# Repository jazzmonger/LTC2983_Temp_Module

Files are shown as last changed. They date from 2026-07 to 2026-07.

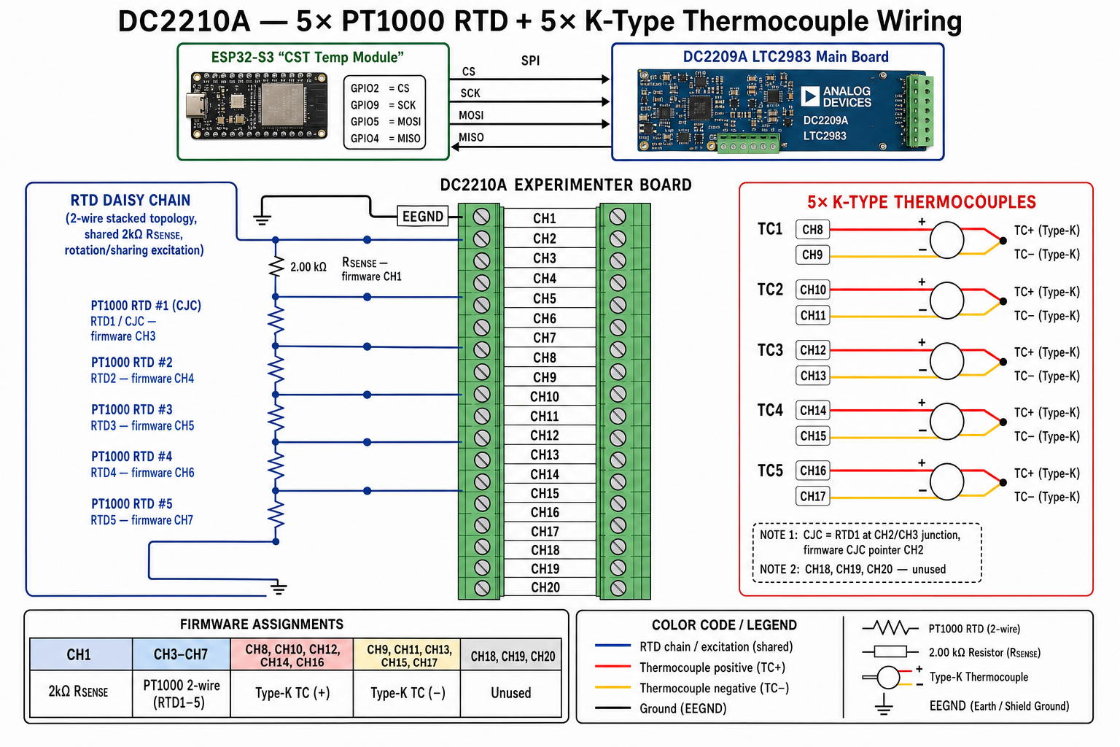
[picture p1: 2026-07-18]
schematics/dc2210a-5rtd-5tc-wiring.png

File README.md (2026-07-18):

# LTC2983 Temperature Module

ESPHome firmware and KiCad hardware designs for reading precision temperature sensors through the [Analog Devices LTC2983](https://www.analog.com/en/products/ltc2983.html) — a 20-channel multi-sensor ADC supporting RTDs, thermocouples, diodes, and thermistors.

This repo is a **standalone** ESPHome device that reads **5× PT1000 RTDs** and **5× K-type thermocouples** in one multi-channel conversion cycle, with per-channel fault sensors. The board and can be adapted to other sensor combinations on unused LTC2983 channels.

## Hardware

| Component | Description |
|---|---|
| **MCU** | ESP32-S3-DevKitC-1 class (16 MB flash, 8 MB octal PSRAM) |
| **Sensor IC** | LTC2983 |
| **Target layout** | Stacked 5 RTD + 5 TC topology ([DC2210A](schematics/dc2210a-5rtd-5tc-wiring.png) reference) |
| **Carrier PCB** | Custom [DC2209A1](KiCad/DC2209A1.kicad_sch) KiCad design — LTC2983 breakout with screw terminals and SPI header |

### SPI wiring (ESP32-S3 → LTC2983)

| Signal | GPIO |
|---|---|
| CS | 2 |
| CLK | 9 |
| MOSI | 5 |
| MISO | 4 |

### Channel map

| Sensor | LTC2983 CH | Type | Notes |
|---|---|---|---|
| RTD 1 | 4 | PT1000, 2-wire | Sense pair CH4 ↔ CH3 (COM) |
| RTD 2 | 6 | PT1000, 2-wire | CH6 ↔ CH5 (COM) |
| RTD 3 | 8 | PT1000, 2-wire | CH8 ↔ CH7 (COM) |
| RTD 4 | 10 | PT1000, 2-wire | CH10 ↔ CH9 (COM) |
| RTD 5 | 12 | PT1000, 2-wire | CH12 ↔ CH11 (COM) |
| TC 1 | 13 | K-type, single-ended | TC− → COM; CJC via CH20 diode |
| TC 2 | 14 | K-type | |
| TC 3 | 15 | K-type | |
| TC 4 | 16 | K-type | |
| TC 5 | 17 | K-type | |

Shared excitation: **CH2** = 2 kΩ sense resistor (RSENSE hub). Odd channels CH3/5/7/9/11 tie to CH2. Cold-junction compensation uses a **2N3906 diode on CH20** (emitter → CH20, base + collector → COM).

See `schematics/dc2210a-5rtd-5tc-wiring.png` and `schematics/dc2210a1-sch.pdf` for full wiring of demo circuit or KiCad schematics for this implementation.

## Firmware

The LTC2983 is driven by a custom C++ handler included directly in the ESPHome config — no external component package required.

| File | Purpose |
|---|---|
| `LTC2983_Temp_Module.yaml` | ESPHome config — 10 template sensors, fault text sensors, 500 ms poll |
| `ltc2983_handler.h` | SPI init, channel assignment, multi-channel conversion, fault decode |
| `common/wifi.yaml` | WiFi / captive portal / web server |

Polling uses non-blocking `read_ltc2983_sensors()`: start a multi-channel conversion (~2 s), publish all channels when DONE, then start the next cycle.

### Home Assistant entities

**Temperature sensors**

- `RTD CH4` … `RTD CH12` — RTD 1–5 (°C)
- `TC 1` … `TC 5` — thermocouples (°C)

**Fault text sensors** (one per channel — `OK`, `Open Circuit`, `Overrange`, etc.)

- `Fault CH4`, `Fault CH6`, `Fault CH8`, `Fault CH10`, `Fault CH12`
- `Fault TC1` … `Fault TC5`

## Project layout

```
LTC2983_Temp_Module.yaml   # ESPHome config
ltc2983_handler.h          # LTC2983 SPI driver
common/wifi.yaml           # WiFi package
schematics/                # Wiring diagrams and reference schematics
KiCad/                     # DC2209A1 carrier board (sch, pcb, gerbers)
Demo Circuit Board/        # Analog Devices DC2209A reference files
LTC2983 sketch and info.c  # Reference channel-config notes
```

## Getting started

### Prerequisites

- [ESPHome](https://esphome.io/) installed
- ESP32-S3-DevKitC-1 connected via USB
- LTC2983 board wired per SPI table and channel map above

### Secrets

Create `secrets.yaml` in the project root (gitignored):

```yaml
wifi_ssid: "YourSSID"
wifi_password: "YourPassword"
```

### Build and flash

Copy to `/tmp` before running ESPHome (avoids path issues):

```bash
cp -r "./LTC2983_Temp_Module" /tmp/ltc2983-temp-module/
cd /tmp/ltc2983-temp-module
esphome run LTC2983_Temp_Module.yaml --device /dev/cu.usbserial-XXXX
```

Replace `/dev/cu.usbserial-XXXX` with your serial port. Logs stream automatically — do not use `--no-logs`.

### Home Assistant

Add the device through the ESPHome integration after flashing. All 10 temperature sensors and 10 fault sensors appear under the `ltc2983-temp-module` device.

## References

- [LTC2983 datasheet](https://www.analog.com/media/en/technical-documentation/data-sheets/ltc2983-2984.pdf)
- [DC2210A demo board](https://www.analog.com/en/resources/evaluation-hardware-and-software/evaluation-boards-kits/dc2210a.html) — 5 RTD + 5 TC reference
- [DC2296A evaluation kit](https://www.analog.com/en/resources/evaluation-hardware-and-software/evaluation-boards-kits/dc2296a.html)
- `schematics/dc2210a1-sch.pdf` — DC2210A schematic
- `schematics/dc2213a1-sch.pdf` — DC2213A schematic (single RTD demo)
- `KiCad/Gerbers/` — fabrication outputs for the DC2209A1 carrier board

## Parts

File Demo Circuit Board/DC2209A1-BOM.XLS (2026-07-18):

Item | Qty | Reference | Part Description | Manufacturer / Part # | Kit Qty
 |  |  |  | NUMBER OF BOARDS = | 275
1 | 21 | C1-C21 | CAP., NP0, 100pF 100V, 5%, 0603 | MURATA, GRM1885C2A101JA01D | 5775
2 | 7 | C22,C24,C25,C30,C31,C33,C34 | CAP., X7R, 10uF 10V, 10%, 0805 | MURATA, GRM21BR71A106KE51L | 1925
3 | 7 | C23,C26,C27,C28,C29,C32,C35 | CAP., X7R, 0.1uF 25V, 10%, 0603 | MURATA, GRM188R71E104KA01D | 1925
4 | 4 | E1,E2,E3,E4 | TURRET, TESTPOINT 0.064" | MILL-MAX, 2308-2-00-80-00-00-07-0 | 1100
5 | 1 | J1 | CONN., 40P, CON-HIROSE-FX2-40P-1.27DS | HIROSE, FX2-40P-1.27DS | 275
6 | 1 | J2 | CONN., HEADER 14POS 2MM VERT GOLD | MOLEX, 87831-1420 | 275
7 | 1 | R1 | RES., CHIP, 1, 1/10W, 5% 0603 | VISHAY, CRCW06031R00FJEA | 275
8 | 1 | R2 | RES., CHIP, 100K, 1/10W, 1% 0603 | VISHAY, CRCW0603100KFKEA | 275
9 | 3 | R3,R4,R5 | RES., CHIP, 4.99K, 1/10W, 1% 0603 | VISHAY, CRCW06034K99FKEA | 825
10 | 1 | U1 | I.C., LTC2983CLX, LQFP48LX-7X7 | LINEAR TECH., LTC2983CLX | 275
11 | 1 | U2 | I.C., 24LC025-I/ST, TSSOP8 | MICROCHIP, 24LC025-I/ST | 275
12 | 2 | MH1,MH2 | STANDOFF, NYLON, 0.25", 1/4" | KEYSTONE, 8831 (SNAP ON) | 550
13 | 2 |  | STENCILS (TOP & BOTTOM) | STENCIL DC2209A-1 | 2

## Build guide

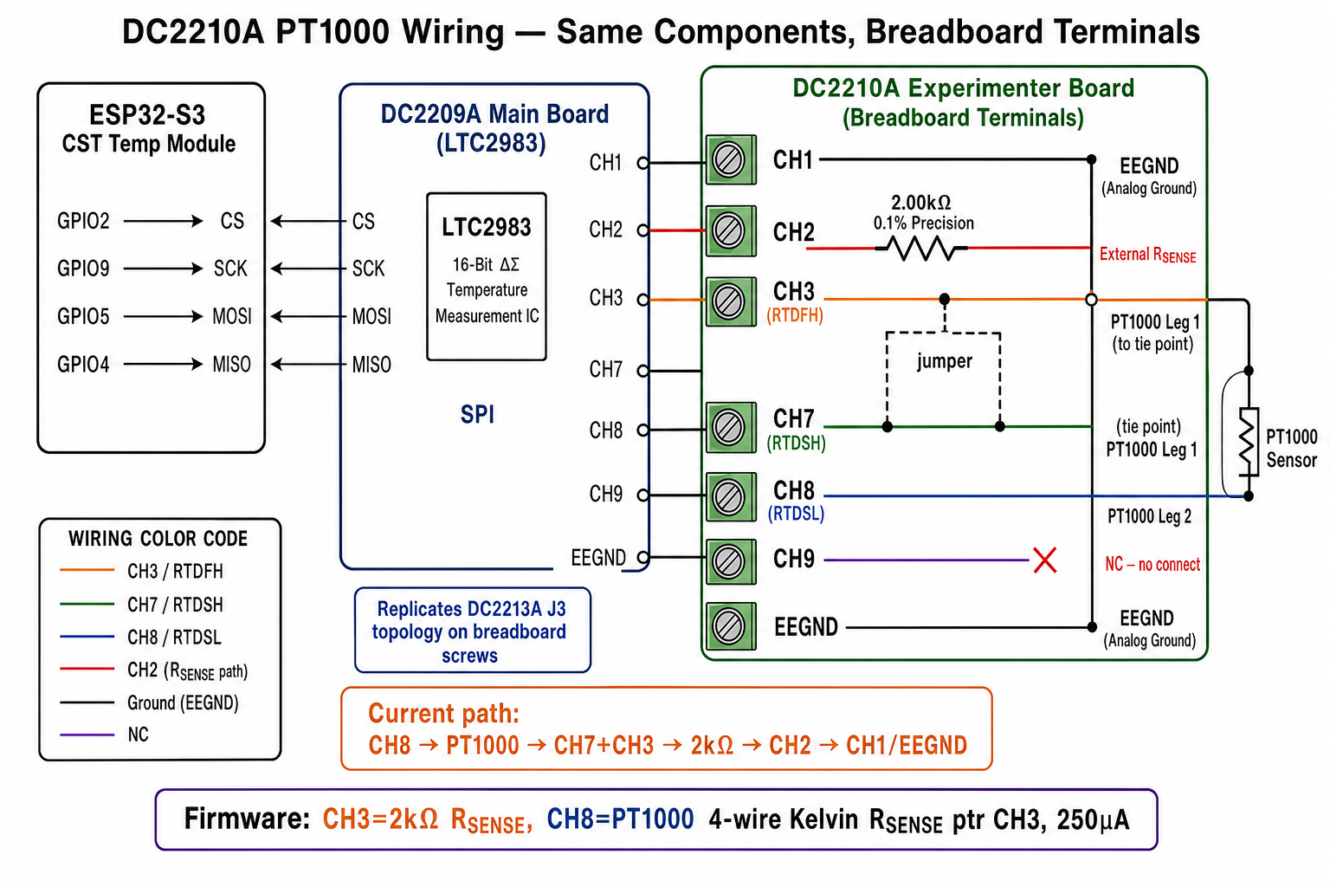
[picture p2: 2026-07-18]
schematics/dc2210a-pt1000-wiring.png

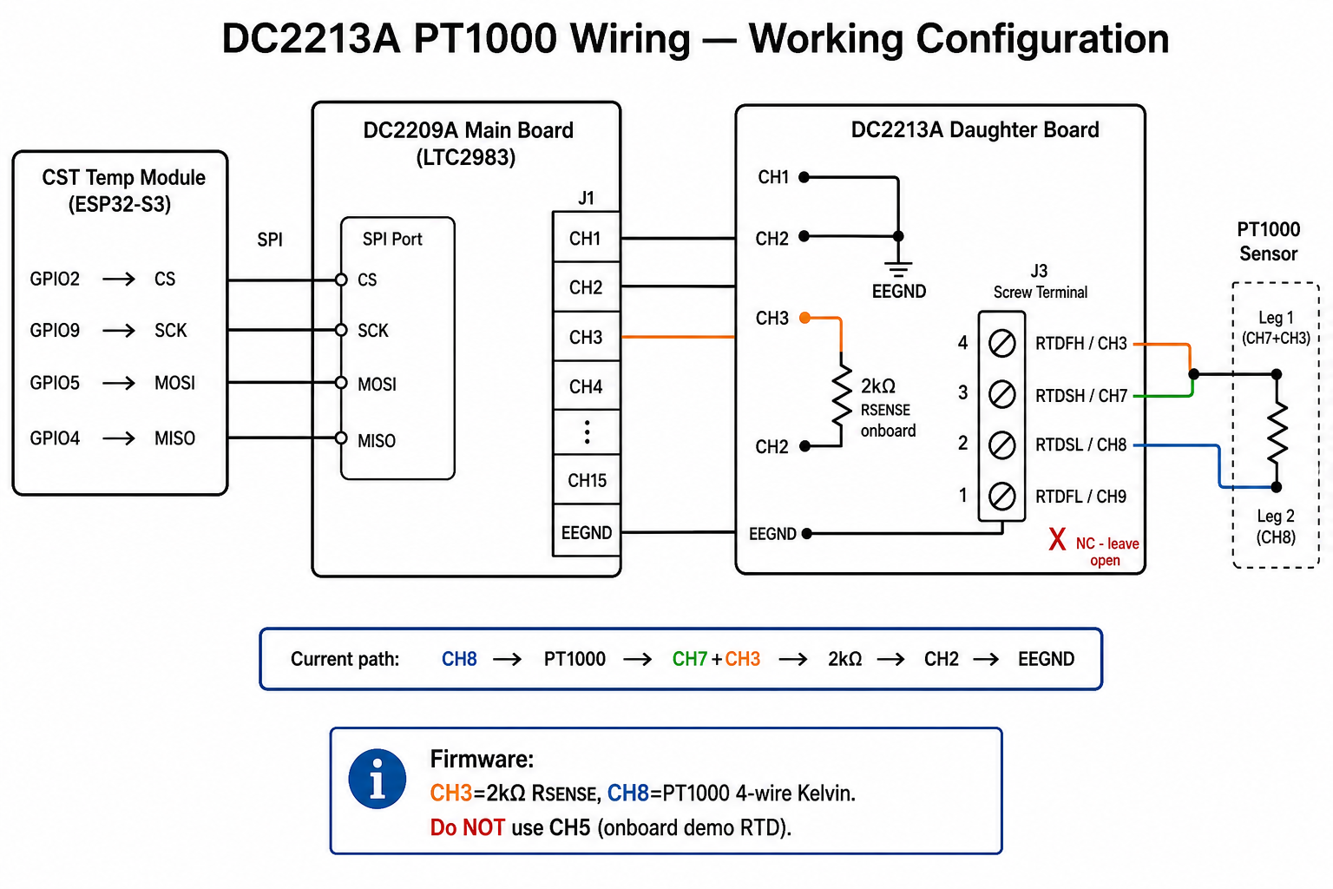
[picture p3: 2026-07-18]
schematics/dc2213a-pt1000-wiring.png

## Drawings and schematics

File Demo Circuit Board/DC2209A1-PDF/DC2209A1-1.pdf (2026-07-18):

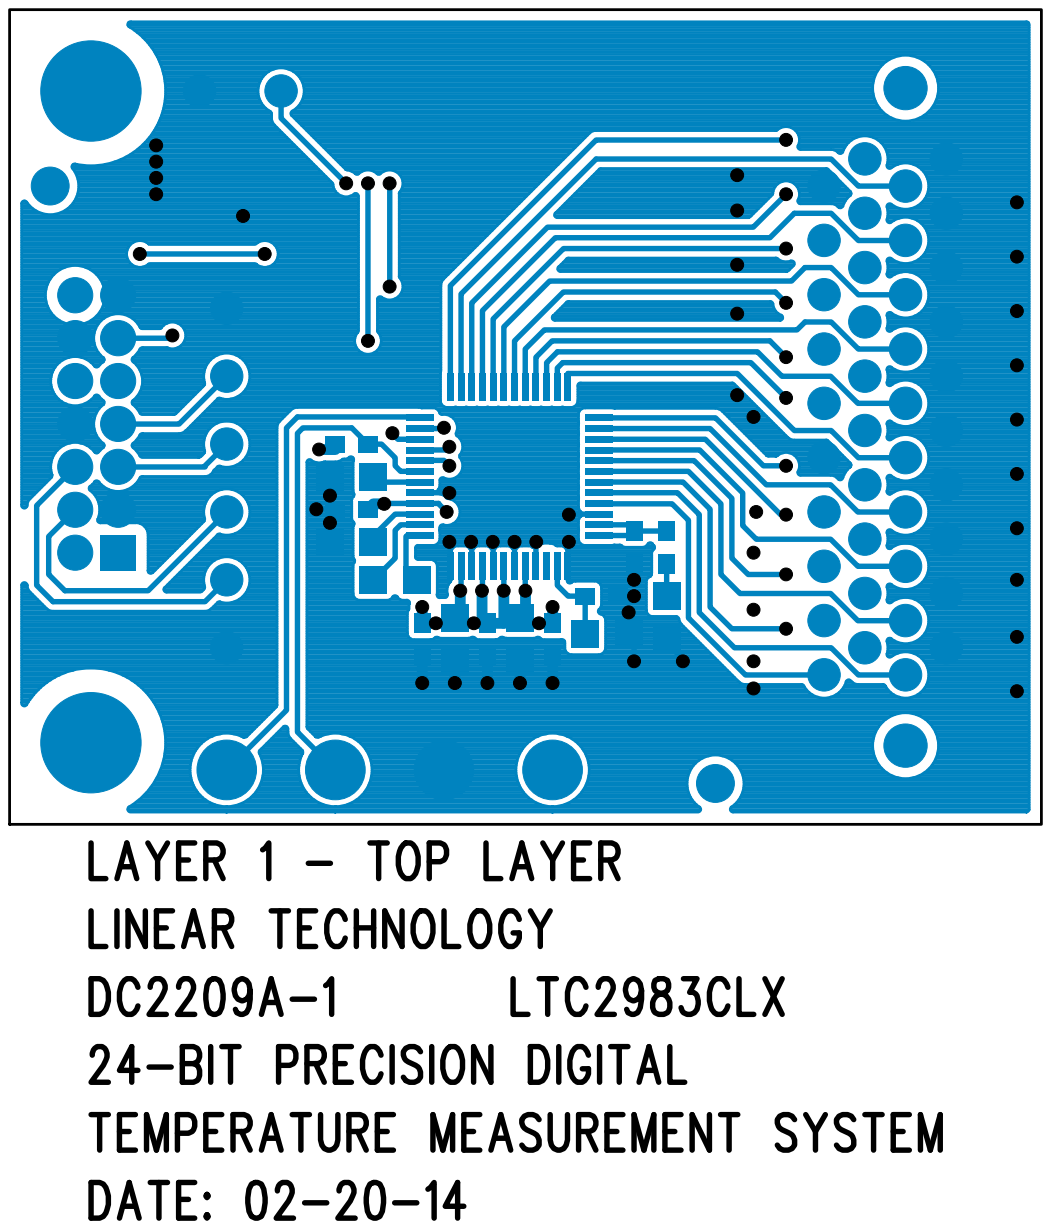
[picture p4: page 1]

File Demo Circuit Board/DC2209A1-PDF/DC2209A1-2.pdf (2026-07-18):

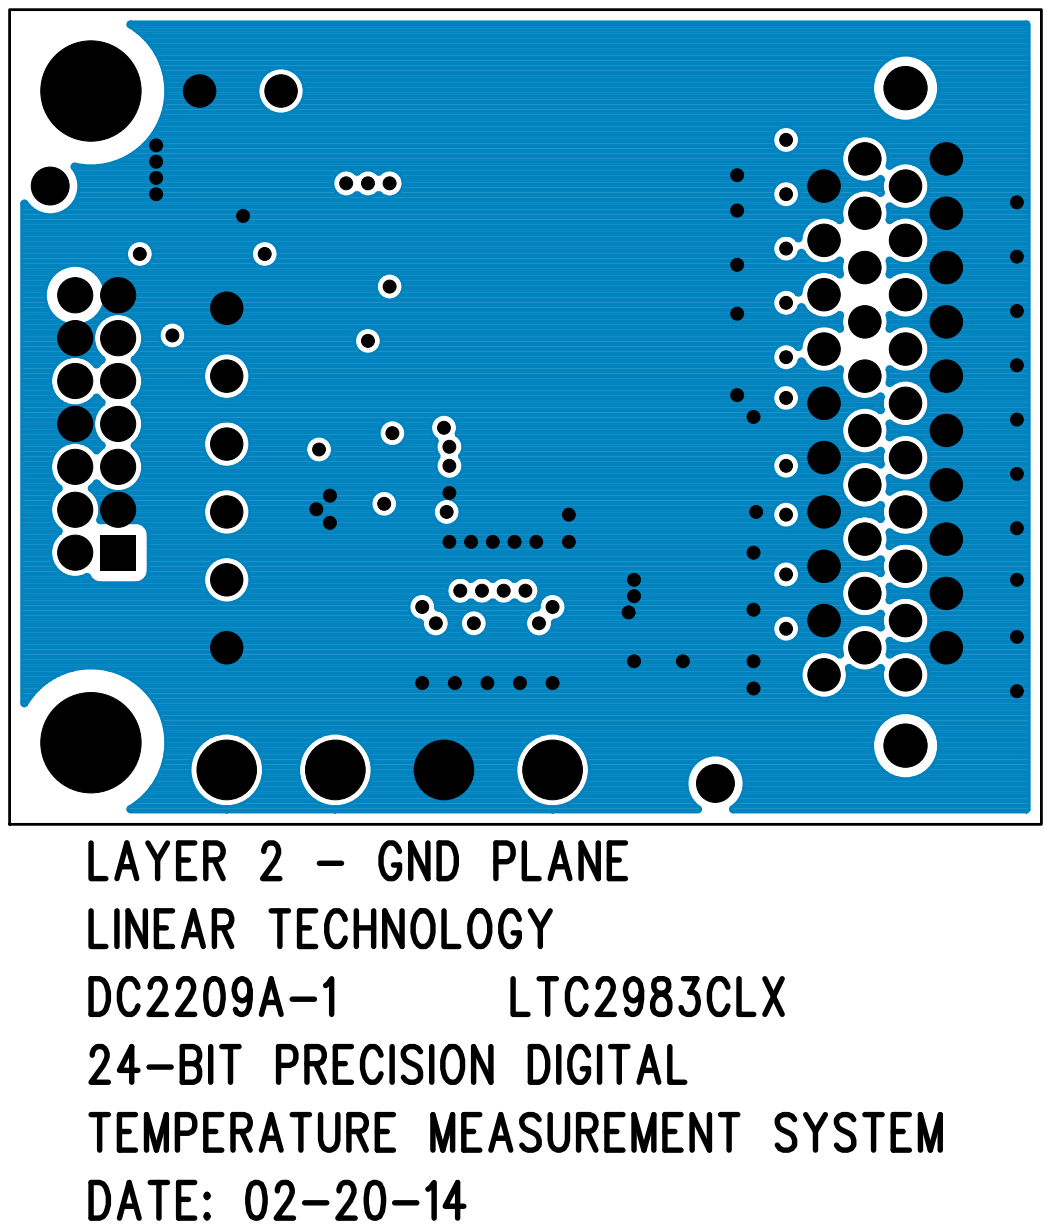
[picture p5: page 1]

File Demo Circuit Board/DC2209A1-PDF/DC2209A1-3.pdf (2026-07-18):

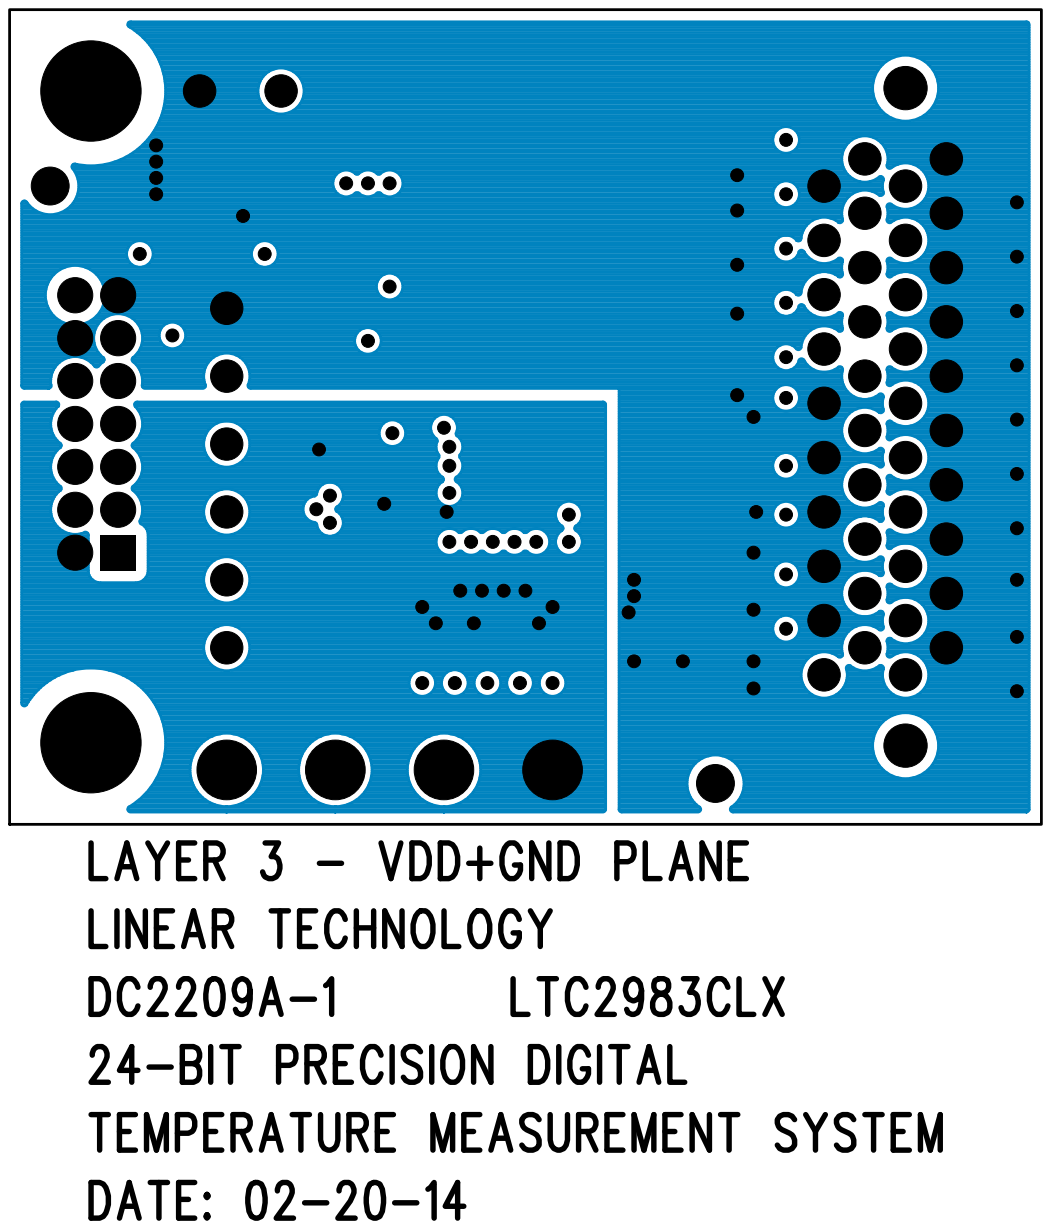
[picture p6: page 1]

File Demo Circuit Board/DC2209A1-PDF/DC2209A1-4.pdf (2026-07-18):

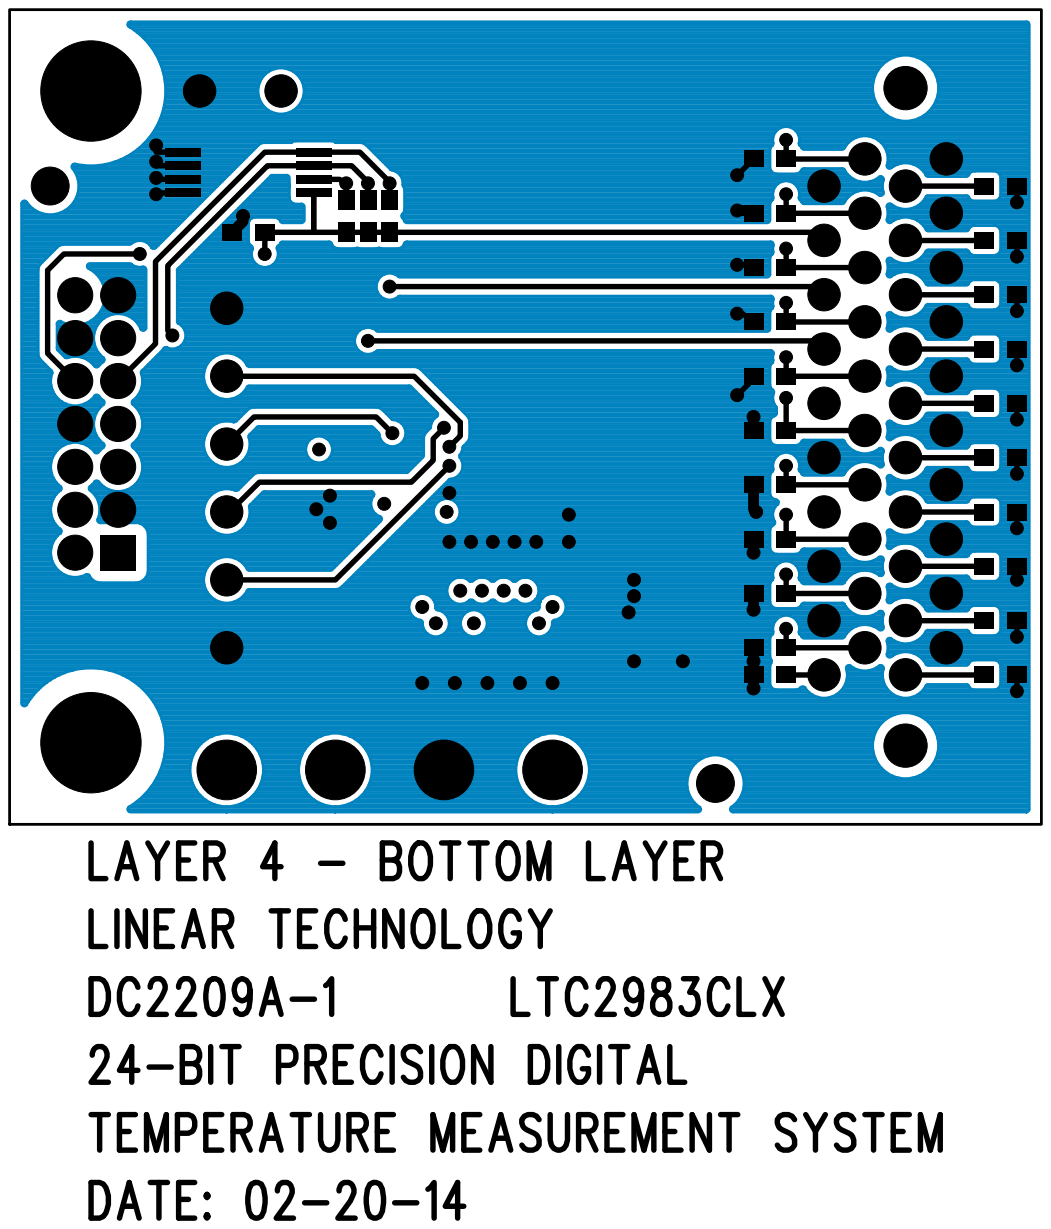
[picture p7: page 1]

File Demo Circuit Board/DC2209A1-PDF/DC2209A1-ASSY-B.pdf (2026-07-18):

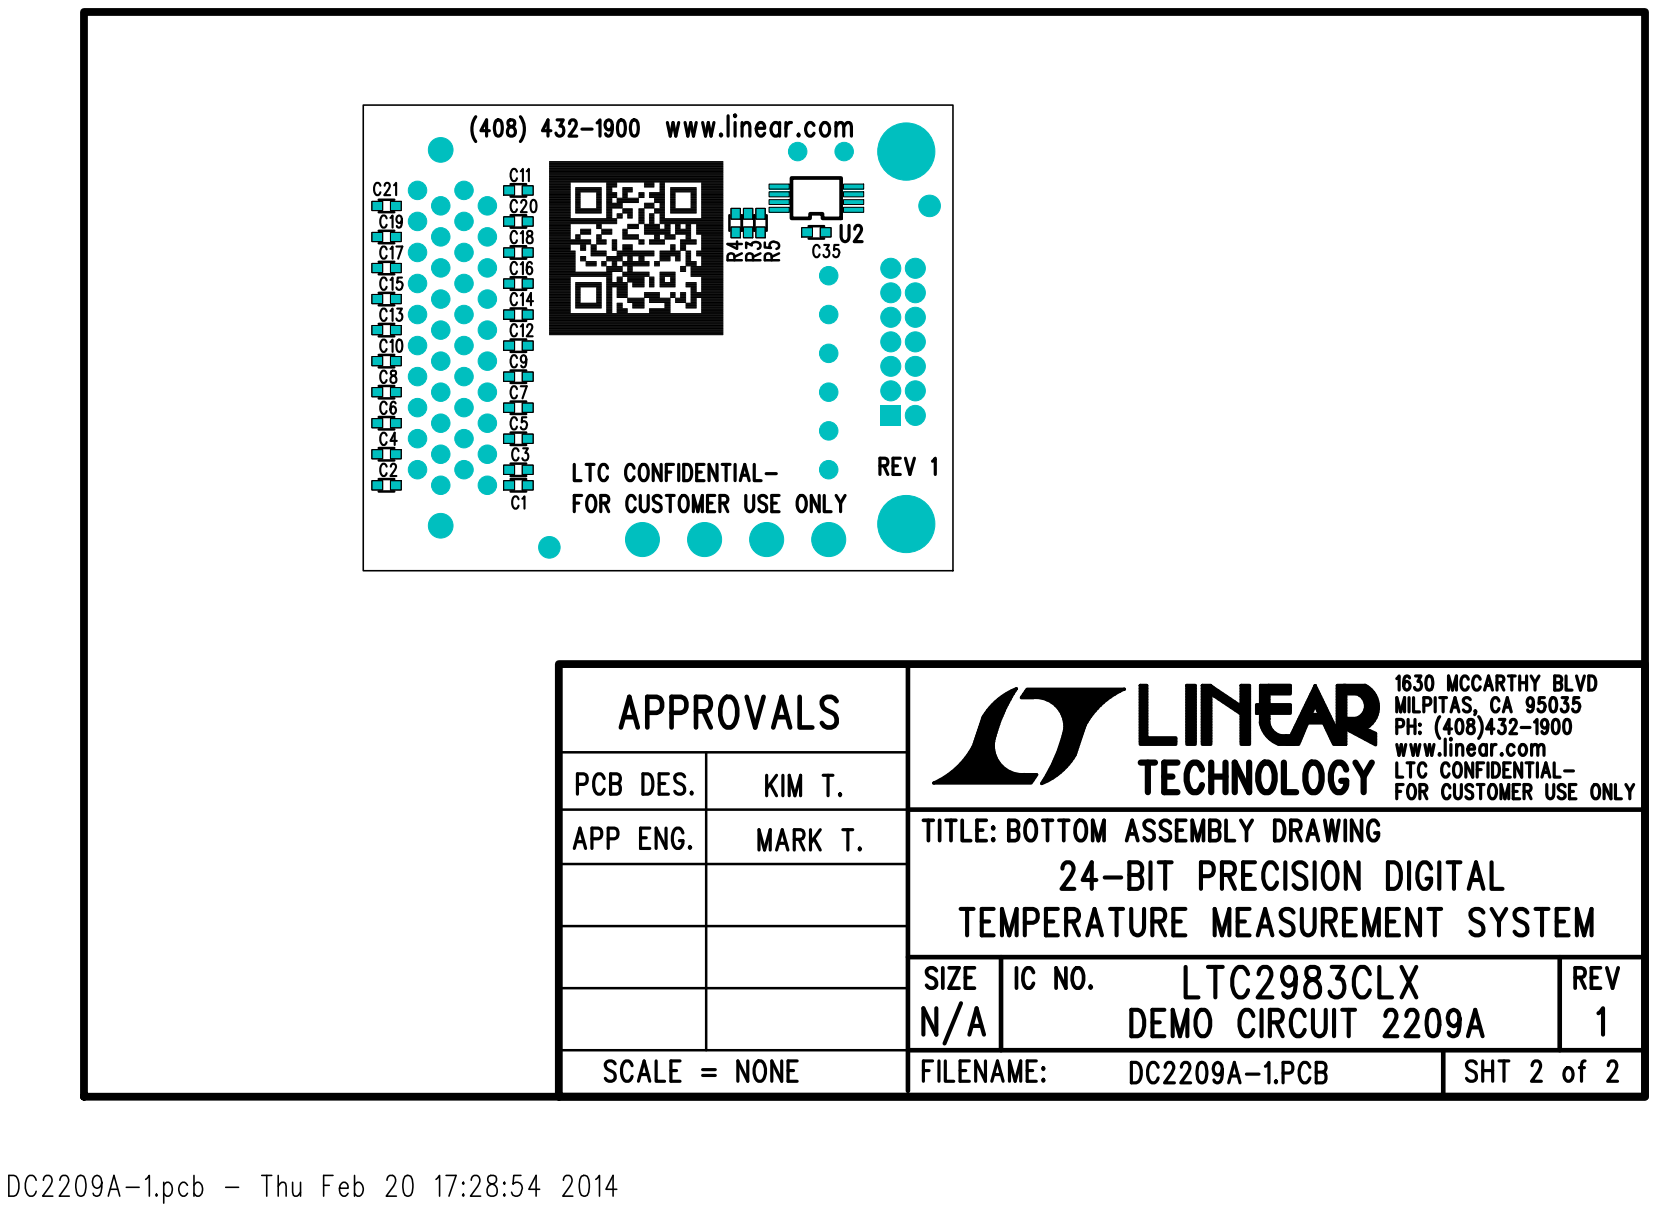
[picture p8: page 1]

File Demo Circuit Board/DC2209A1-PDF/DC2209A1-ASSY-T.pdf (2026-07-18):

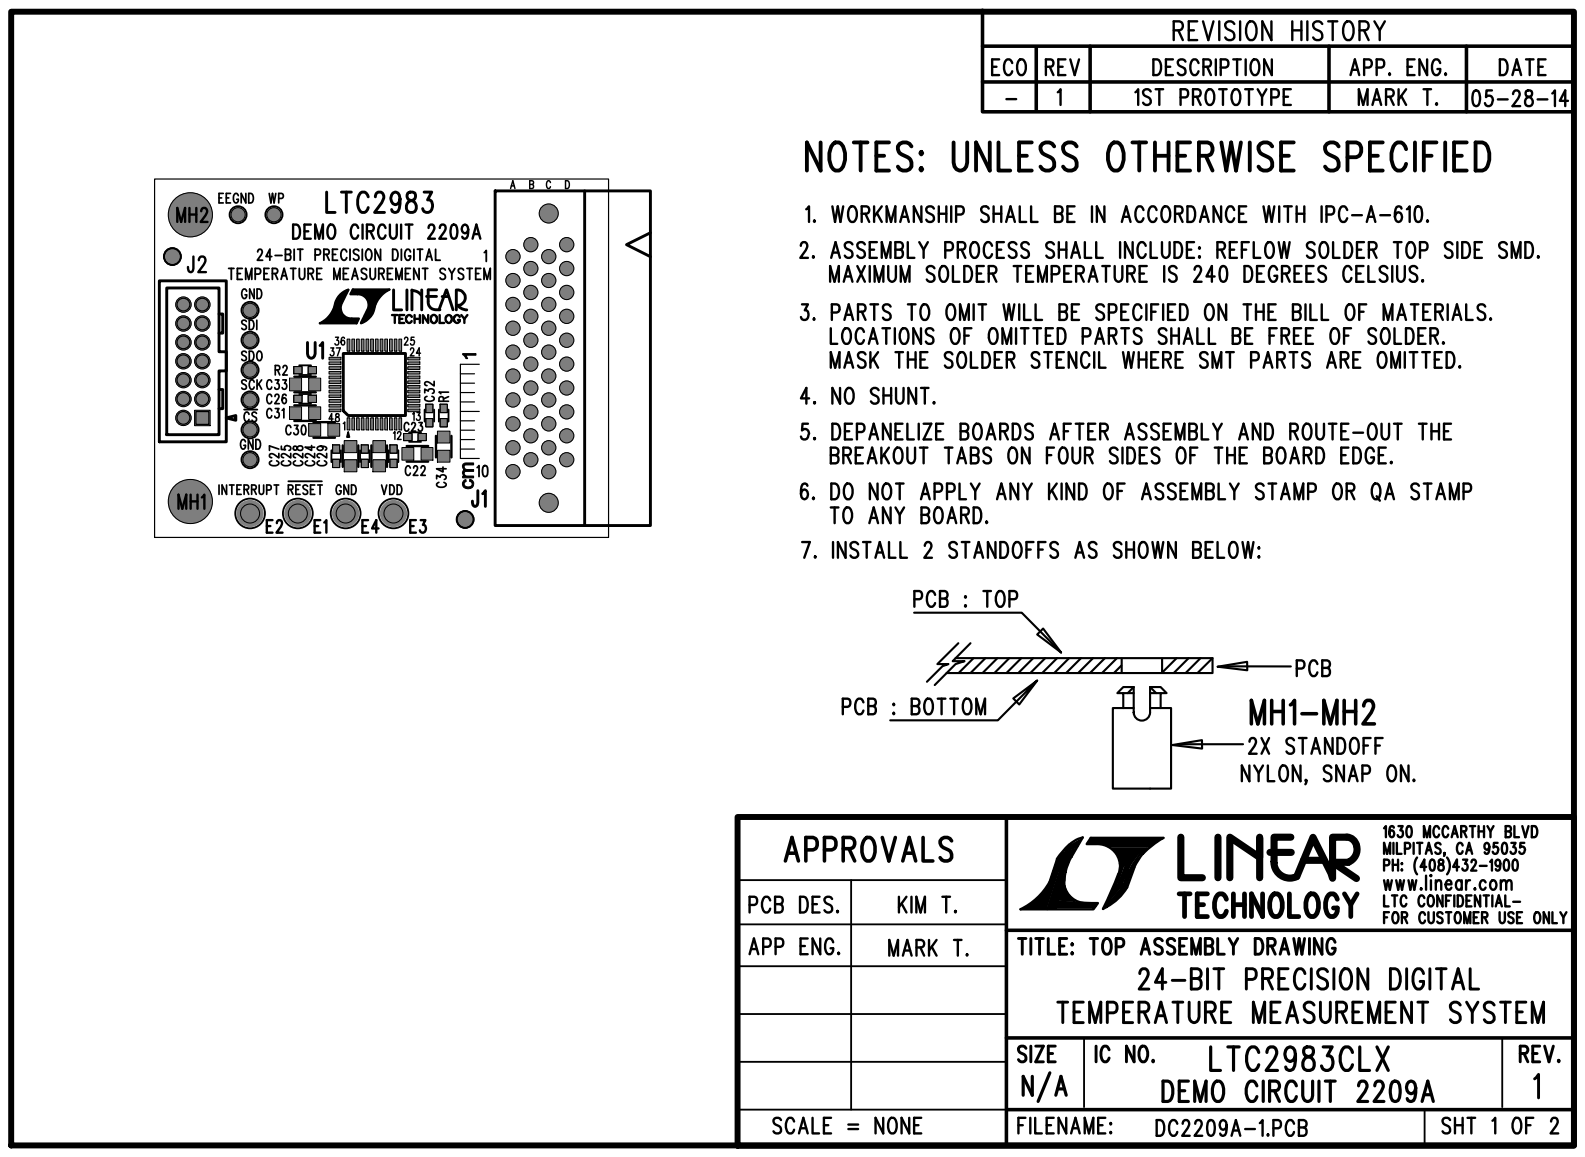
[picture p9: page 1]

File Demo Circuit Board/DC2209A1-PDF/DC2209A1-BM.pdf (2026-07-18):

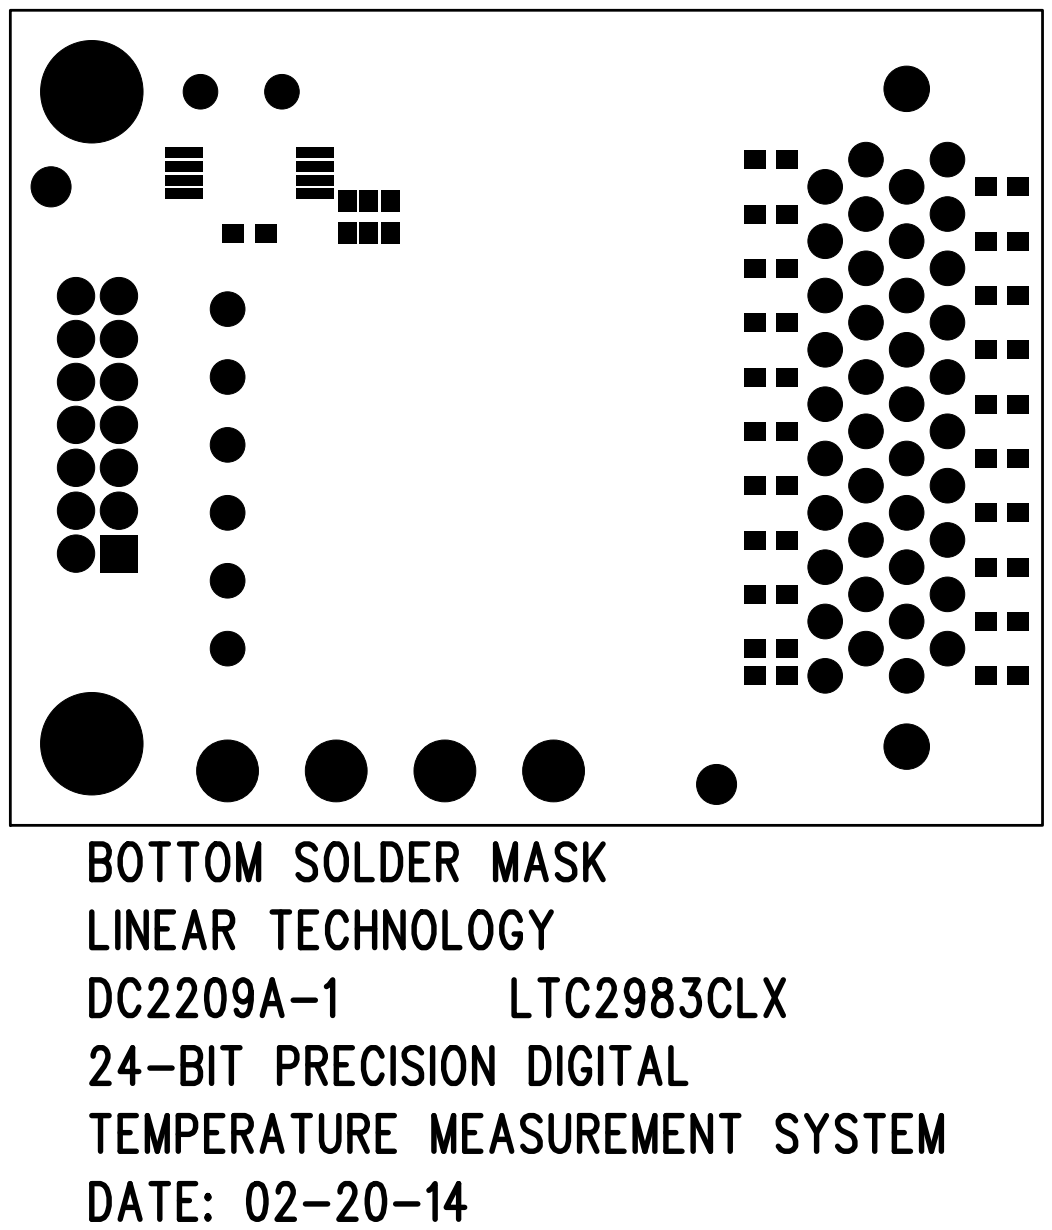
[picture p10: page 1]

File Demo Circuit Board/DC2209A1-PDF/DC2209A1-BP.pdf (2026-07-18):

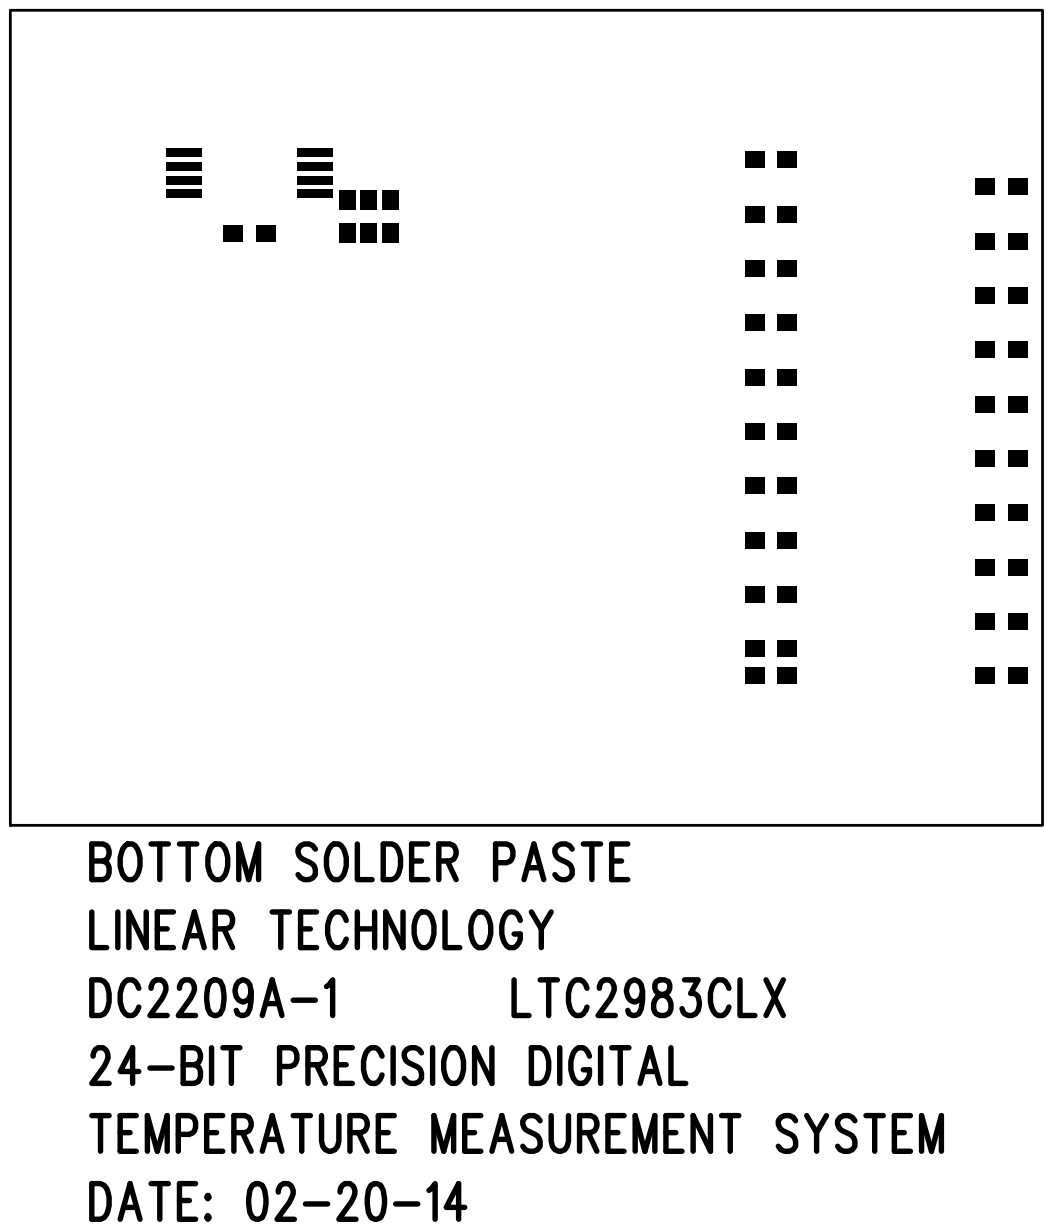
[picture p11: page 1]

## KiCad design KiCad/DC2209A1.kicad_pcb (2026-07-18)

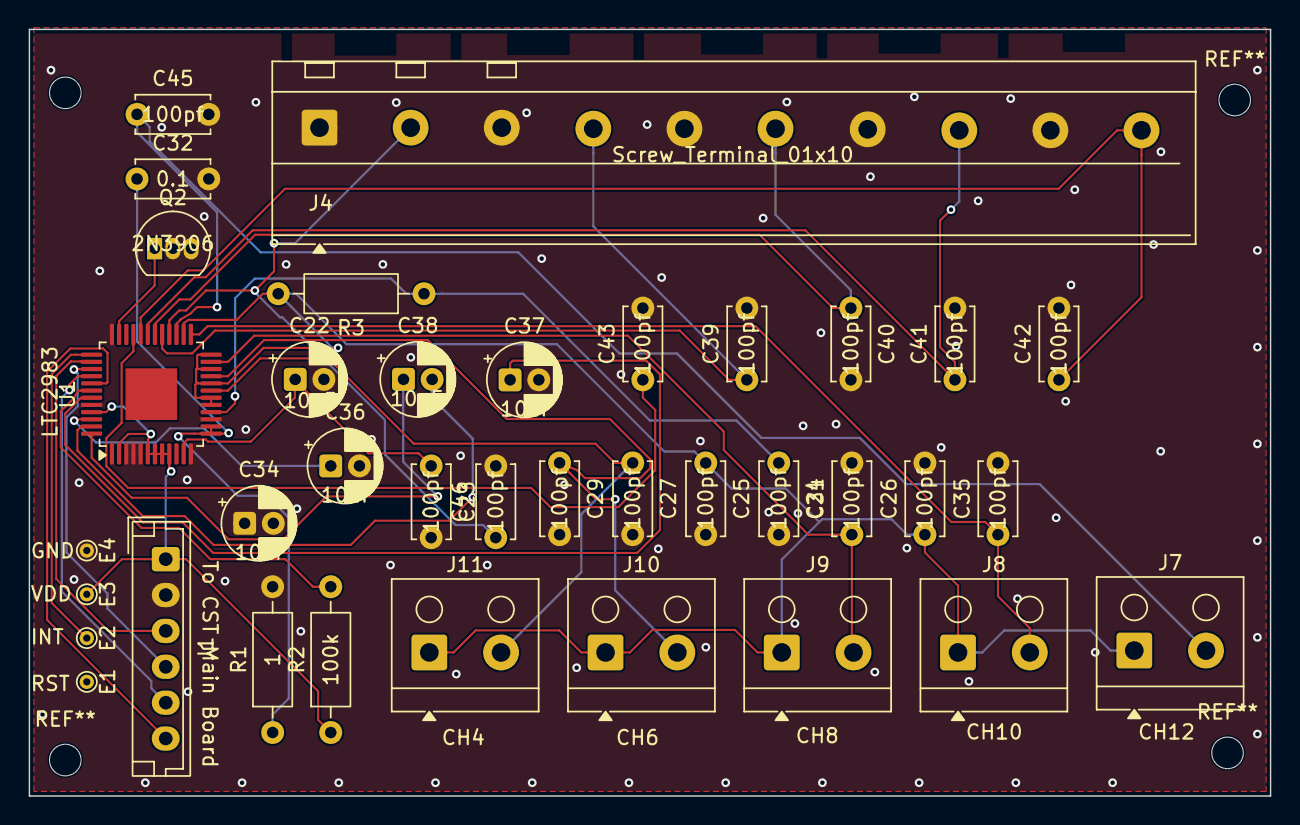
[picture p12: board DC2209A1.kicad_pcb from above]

Board: 2 copper layers, 86.5 x 53.4 mm, 37 parts (0 on the bottom side), 28 nets.

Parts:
C22, C34, C36, C37, C38: 10uF; CP_Radial_D5.0mm_P2.00mm
C23, C24, C25, C26, C27, C29, C31, C35, C39, C40, C41, C42, C43, C45, C46: 100pf; C_Disc_D5.0mm_W2.5mm_P5.00mm
C32: 0.1; C_Disc_D5.0mm_W2.5mm_P5.00mm
E1, E2, E3, E4: TestPoint; TestPoint_THTPad_D1.0mm_Drill0.5mm
J1: JST_XH_01x06; JST_EH_B6B-EH-A_1x06_P2.50mm_Vertical
J4: Screw_Terminal_01x10; TerminalBlock_10x03_P6.35mm_M3_screws
J7: CH12; TerminalBlock_RND_205-00001_1x02_P5.00mm_Horizontal
J8: CH10; TerminalBlock_RND_205-00001_1x02_P5.00mm_Horizontal
J9: CH8; TerminalBlock_RND_205-00001_1x02_P5.00mm_Horizontal
J10: CH6; TerminalBlock_RND_205-00001_1x02_P5.00mm_Horizontal
J11: CH4; TerminalBlock_RND_205-00001_1x02_P5.00mm_Horizontal
Q2: 2N3906; TO-92_Inline
R1: 1; R_Axial_DIN0207_L6.3mm_D2.5mm_P10.16mm_Horizontal
R2: 100k; R_Axial_DIN0207_L6.3mm_D2.5mm_P10.16mm_Horizontal
R3: 2k; R_Axial_DIN0207_L6.3mm_D2.5mm_P10.16mm_Horizontal
U1: LTC2983; LQFP-48-1EP_7x7mm_P0.5mm_EP3.6x3.6mm

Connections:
/CH20: Q2.1 (E), U1.35 (CH20)
/INTERRUPT: E2.1 (1_1), U1.37 (INTERRUPT)
/LDO: C37.1, U1.43 (LDO)
/NCS: J1.6, U1.41 (NCS)
/Q1: C38.1, U1.48 (Q1)
/Q2: C38.2, U1.47 (Q2)
/Q3: C36.1, U1.46 (Q3)
/RESETN: R2.2, U1.42 (RESETN)
/SCK: J1.3, U1.38 (SCK)
/SDI: J1.5, U1.40 (SDI)
/SDO: J1.4, U1.39 (SDO)
/VREFOUT: C32.1, R1.1, U1.13 (VREFOUT), U1.14 (VREFP)
/VREF_BYP: C22.1, C23.1, U1.11 (VREF_BYP)
CH1: C24.1, R3.1, U1.16 (CH1)
CH2: C25.1, C26.1, J7.1, J8.1, J9.1, J10.1, J11.1, R3.2, U1.17 (CH2), U1.18 (CH3), U1.20 (CH5), U1.22 (CH7), U1.24 (CH9), U1.26 (CH11)
CH4: C27.1, J11.2, U1.19 (CH4)
CH6: C29.1, J10.2, U1.21 (CH6)
CH8: C31.1, J9.2, U1.23 (CH8)
CH10: C35.1, J8.2, U1.25 (CH10)
CH12: C45.1, J7.2, U1.27 (CH12)
CH13: C46.1, J4.2, U1.28 (CH13)
CH14: C39.1, J4.4, U1.29 (CH14)
CH15: C40.1, J4.6, U1.30 (CH15)
CH16: C41.1, J4.8, U1.31 (CH16)
CH17: C42.1, J4.10, U1.32 (CH17)
CH18: C43.1, U1.33 (CH18)
GND: C22.2, C23.2, C24.2, C25.2, C26.2, C27.2, C29.2, C31.2, C32.2, C34.1, C34.2, C35.2, C36.2, C37.2, C39.2, C40.2, C41.2, C42.2, C43.2, C45.2, C46.2, E4.1 (1_1), J1.2, J4.1, J4.3, J4.5, J4.7, J4.9, Q2.2 (B), Q2.3 (C), R1.2, U1.1 (GND), U1.3 (GND), U1.4 (GND), U1.5 (GND), U1.12 (GND), U1.15 (GND), U1.36 (COM), U1.44 (GND)
VDD: E3.1 (1_1), J1.1, R2.1, U1.2 (VDD), U1.6 (VDD), U1.7 (VDD), U1.8 (VDD), U1.9 (VDD), U1.45 (VDD)

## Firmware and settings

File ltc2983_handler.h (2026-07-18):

#pragma once
#include "esphome.h"
#include "esphome/core/log.h"
#include "driver/gpio.h"
#include "driver/spi_master.h"
#include <cmath>
#include <cstring>

static const char *const TAG = "LTC2983";

// Independent 2-wire PT1000s (any one open leaves the others valid):
//   CH1 = RSENSE return (→GND)
//   CH2 = 2 kΩ RSENSE (shared excitation hub / COM)
//   Odd channels CH3/5/7/9/11 hard-tied to CH2 (not assigned as sensors)
//   Even sense channels — each RTD wired between that CH and the prior odd hub:
//     RTD1: CH4 ↔ CH3(=COM)   read CH4
//     RTD2: CH6 ↔ CH5(=COM)   read CH6
//     RTD3: CH8 ↔ CH7(=COM)   read CH8
//     RTD4: CH10 ↔ CH9(=COM)  read CH10
//     RTD5: CH12 ↔ CH11(=COM) read CH12
//   K-type TCs single-ended (TC− → COM): TC+ on CH13–CH17
//   CJC: 2N3906 diode on CH20 — emitter→CH20, base+collector→COM
//
// Conversion: multi-channel mask (0x00F4–0x00F7) + start 0x80 — one wait for all.

#define LTC2983_COMMAND_STATUS_REG  0x0000
#define LTC2983_GLOBAL_CONFIG_REG   0x00F0
#define LTC2983_MULT_CH_MASK_BASE   0x00F4
#define LTC2983_MUX_CONFIG_REG      0x00FF
#define LTC2983_CH_ASSIGN_BASE      0x0200
#define LTC2983_DATA_BASE           0x0010

#define STATUS_DONE_MASK    0x40
#define STATUS_START_MASK   0x80
#define CONV_START_MULTI    0x80  // B7=1, B4:0=00000 → multi-channel

// Shared SPI2 with MCP3208 (ESPHome spi_bus in packages/io_gpio.yaml). CS is GPIO bit-bang.
#define LTC2983_CS_PIN      GPIO_NUM_2
#define LTC2983_SPI_HOST    SPI2_HOST
#define LTC2983_SPI_CLK     GPIO_NUM_9
#define LTC2983_SPI_MOSI    GPIO_NUM_5
#define LTC2983_SPI_MISO    GPIO_NUM_4
#define LTC2983_SPI_HZ      4000000

#define CH_RSENSE   2
#define CH_RTD_1    4
#define CH_RTD_2    6
#define CH_RTD_3    8
#define CH_RTD_4   10
#define CH_RTD_5   12
#define CH_TC_1    13
#define CH_TC_2    14
#define CH_TC_3    15
#define CH_TC_4    16
#define CH_TC_5    17
#define CH_DIODE_P 20

#define NUM_RTD  5
#define NUM_TC   5

#define CFG_RSENSE ((uint32_t)0x1D << 27) | 0x001F4000UL
#define CFG_RTD_PT1000 ((uint32_t)0x0F << 27) | ((uint32_t)CH_RSENSE << 22) \
                       | (0x1UL << 18) | (0x5UL << 14)
// Independent pairs: minimal extra settle (base 1 ms + 2×100 µs)
#define MUX_SETTLE_LSB  2
#define CFG_DIODE_CJC ((uint32_t)0x1C << 27) | (7UL << 24) | (3UL << 22)
#define CFG_TC_K_SE ((uint32_t)0x02 << 27) | ((uint32_t)CH_DIODE_P << 22) \
                     | (1UL << 21) | (0x1UL << 20)

static constexpr uint8_t RTD_CHANNELS[NUM_RTD] = {
    CH_RTD_1, CH_RTD_2, CH_RTD_3, CH_RTD_4, CH_RTD_5,
};
static constexpr uint8_t TC_CHANNELS[NUM_TC] = {
    CH_TC_1, CH_TC_2, CH_TC_3, CH_TC_4, CH_TC_5,
};
static constexpr float TC_TEMP_MIN_C = -200.0f;
static constexpr float TC_TEMP_MAX_C = 1370.0f;

enum FaultCode : uint8_t {
  FAULT_OK = 0,
  FAULT_OPEN,
  FAULT_SHORT_VDD,
  FAULT_OVERRANGE,
  FAULT_UNDERRANGE,
  FAULT_HARD,
  FAULT_TIMEOUT,
  FAULT_INVALID,
};

static const char *const FAULT_TEXT[] = {
    "OK",
    "Open Circuit",
    "Short to VDD",
    "Overrange",
    "Underrange",
    "Hard Failure",
    "General Fault",
    "Invalid",
};

struct LtcSensors {
  esphome::template_::TemplateSensor *rtd[NUM_RTD];
  esphome::template_::TemplateSensor *tc[NUM_TC];
  esphome::text_sensor::TextSensor *fault_rtd[NUM_RTD];
  esphome::text_sensor::TextSensor *fault_tc[NUM_TC];
};

static spi_device_handle_t ltc2983_spi_device = nullptr;
static bool ltc2983_initialized = false;
static bool ltc2983_spi_bus_ready = false;
static bool ltc2983_absent = false;
static uint32_t ltc2983_next_init_ms = 0;
static bool ltc_conv_pending = false;
static uint32_t ltc_conv_start_ms = 0;
static uint8_t conversion_mask_[4] = {};

static void ltc2983_cs_low()  { gpio_set_level(LTC2983_CS_PIN, 0); }
static void ltc2983_cs_high() { gpio_set_level(LTC2983_CS_PIN, 1); }

static bool spi_xfer(const uint8_t *tx, uint8_t *rx, size_t len) {
  spi_transaction_t t = {};
  t.length    = len * 8;
  t.tx_buffer = tx;
  t.rx_buffer = rx;
  return spi_device_polling_transmit(ltc2983_spi_device, &t) == ESP_OK;
}

static void write_byte(uint16_t reg, uint8_t data) {
  uint8_t tx[4] = {0x02, (uint8_t)(reg >> 8), (uint8_t)reg, data};
  ltc2983_cs_low();
  spi_xfer(tx, nullptr, 4);
  ltc2983_cs_high();
}

static void write_dword(uint16_t reg, uint32_t data) {
  uint8_t tx[7] = {
      0x02, (uint8_t)(reg >> 8), (uint8_t)reg,
      (uint8_t)(data >> 24), (uint8_t)(data >> 16),
      (uint8_t)(data >> 8), (uint8_t)data,
  };
  ltc2983_cs_low();
  spi_xfer(tx, nullptr, 7);
  ltc2983_cs_high();
}

static uint8_t read_byte(uint16_t reg) {
  uint8_t tx[4] = {0x03, (uint8_t)(reg >> 8), (uint8_t)reg, 0x00};
  uint8_t rx[4] = {};
  ltc2983_cs_low();
  spi_xfer(tx, rx, 4);
  ltc2983_cs_high();
  return rx[3];
}

static uint32_t read_dword(uint16_t reg) {
  uint8_t tx[7] = {0x03, (uint8_t)(reg >> 8), (uint8_t)reg, 0, 0, 0, 0};
  uint8_t rx[7] = {};
  ltc2983_cs_low();
  spi_xfer(tx, rx, 7);
  ltc2983_cs_high();
  return ((uint32_t)rx[3] << 24) | ((uint32_t)rx[4] << 16) |
         ((uint32_t)rx[5] << 8) | (uint32_t)rx[6];
}

static inline uint16_t ch_assign_addr(uint8_t ch) {
  return LTC2983_CH_ASSIGN_BASE + (uint16_t)(ch - 1) * 4;
}

static inline uint16_t ch_data_addr(uint8_t ch) {
  return LTC2983_DATA_BASE + (uint16_t)(ch - 1) * 4;
}

// Datasheet Table 65: 0x0F4 reserved; 0x0F5 B7..B4 = CH20..17;
// 0x0F6 B7..B0 = CH16..9; 0x0F7 B7..B0 = CH8..1
static void mask_set_channel(uint8_t mask[4], uint8_t ch) {
  if (ch < 1 || ch > 20) return;
  if (ch <= 8)
    mask[3] |= (uint8_t)(1u << (ch - 1));
  else if (ch <= 16)
    mask[2] |= (uint8_t)(1u << (ch - 9));
  else
    mask[1] |= (uint8_t)(1u << (ch - 13));
}

static void build_conversion_mask() {
  memset(conversion_mask_, 0, 4);
  for (uint8_t ch : RTD_CHANNELS) mask_set_channel(conversion_mask_, ch);
  for (uint8_t ch : TC_CHANNELS) mask_set_channel(conversion_mask_, ch);
  // CH20 diode is not in the mask — each TC conversion measures CJC via its
  // assignment-word pointer (saves one full ADC cycle ≈ 170 ms).
}
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

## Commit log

2026-06-04 Initial commit — LTC2983 ESPHome custom component
    ESP32-S3 firmware for the CST Temp Module reading a PT1000 RTD and
    K-type thermocouple via an LTC2983 24-bit temperature measurement IC
    (DC2209A + DC2210A eval boards). Custom SPI driver in ltc2983_handler.h
    with channel configuration for CH1=RSENSE, CH2=PT1000, CH5=TC-K.
2026-06-05 Fix DC2213A J3 PT1000 on CH8 instead of onboard CH5.
    The external RTD connector maps to CH3/CH7/CH8/CH9 per the DC2213A schematic; firmware now uses CH8 4-wire Kelvin with the onboard 2kΩ RSENSE on CH3 so the sensor responds to real temperature changes.
    [ltc2983_handler.h]
2026-07-18 Expand README, rename ESPHome config, and add DC2209A hardware assets.
    Document the LTC2983 PT1000 setup, rename cst-temp-module.yaml to LTC2983_Temp_Module.yaml, and add KiCad carrier board, demo board reference files, and wiring diagrams.
    [DC2209A-1.DSN, DC2209A1-BOM.XLS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]
2026-07-18 Add 5 RTD + 5 thermocouple multi-channel support from CST_5Pot.
    Replace single PT1000 polling with the full stacked channel map, fault sensors, and non-blocking multi-channel driver so the standalone module matches production IO firmware.
    [ltc2983_handler.h]
